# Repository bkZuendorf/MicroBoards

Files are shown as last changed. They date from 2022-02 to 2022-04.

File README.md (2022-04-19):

# CRBK-MicroBoards

In diesem Projekt werden µC-Boards bereitgestellt, die im Rahmen des Unterrichts am CRBK entstanden sind.

## Integration der Boards in die Arduino IDE
Um die Boards innerhalb der Arduino IDE nutzen zu können, müssen folgende Schritte durchgeführt werden:
- Ergänzung der Boardverwalter URL in der Arduino-IDE (unter Datei/Voreinstellungen) um die Adresse zur JSON Datei: https://raw.githubusercontent.com/bkZuendorf/MicroBoards/main/package_crbk_index.json
- Öffne in der Arduino-IDE unter Werkzeuge/Board/ den Boardverwalter
- Suche nach CRBK
- Installiere CRBK Mikrocontroller Boards

## Boards
Im Augenblick steht ein einfaches Board zur Verfügung.

### TinyRuler
Der TinyRuler ist das erste Board des CRBKs auf Basis eine ATTiny 84A. Ziel war es ein einfaches Board zum direkten Programmieren über den USB-Port zu erzeugen. Das Board ist lediglich dazu gedacht 5 LEDs abhängig von einem Lagesensor anzusprechen. Der erste Entwurf sah die Verwendung der Platinen innerhalb eines 3-D gedruckten Lineals vor. So kann mit Anheben des Lineals die Animation der LEDs verändert werden. Besonderes Augenmerk galt der energiesparenden Umsetzung der Lösung.
Das Board benötigt im Tiefschlafmodus weniger als 1µA und lässt so mit einer 200mAh Knopfzelle eine mehrmonatige Nutzung zu. 

Im Rahmen der Ausrichtung des Girls' Day wurde die Platine als Bestandteil eines Lineals vorgesehen. Das "Meldelineal" für Schülerinnen und Schüler wurde wir folgt gestaltet:
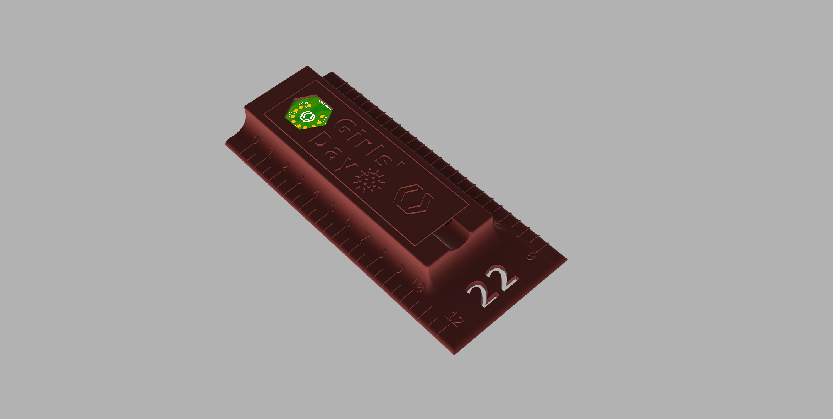
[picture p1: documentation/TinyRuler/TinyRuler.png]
Design für den Girls' Day


Das [Video](https://www.abitur-am-berufskolleg.info/wp-content/uploads/2021/11/TinyRuler.mp4) zeigt das geplante Aussehen in einer ersten Version.

Ein Video des fertigen Exponats folgt ...

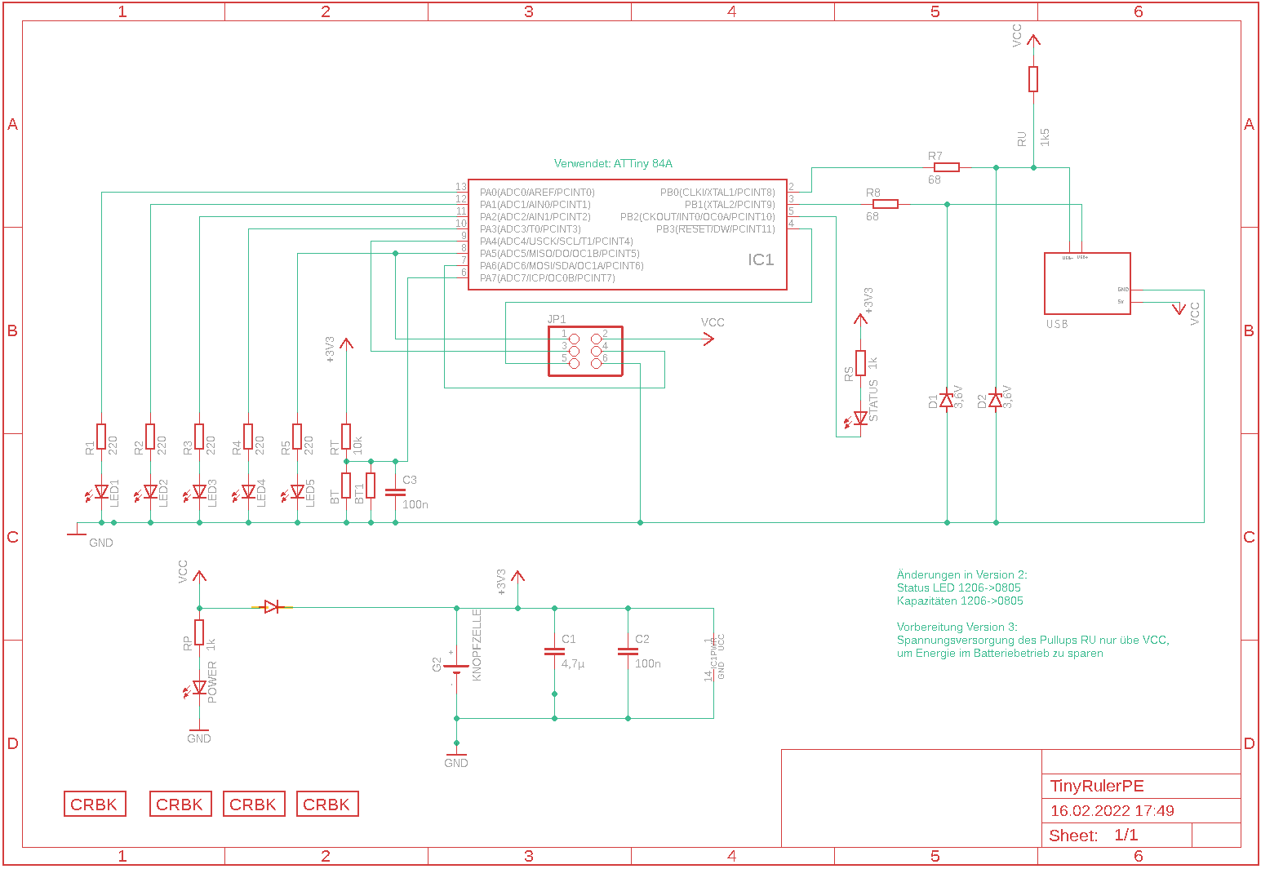
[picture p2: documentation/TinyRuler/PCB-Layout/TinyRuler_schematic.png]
Schematic

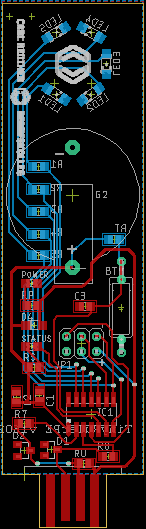
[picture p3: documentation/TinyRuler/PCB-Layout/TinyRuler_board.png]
Board


Das [Eagle Layout](https://github.com/bkZuendorf/MicroBoards/tree/main/documentation/TinyRuler/PCB-Layout) kann verwendet werden, um die Platine nachzubauen.
Die [Fusion CAD-Datei](https://github.com/bkZuendorf/MicroBoards/tree/main/documentation/TinyRuler/Fusion-Design) dient der Erzeugung einer 3D-Druck Datei.

#### Treiber
Zur Verwendung des TinyRuler ist die Installation eines Treibers erforderlich. Dies kann entsprechend der Anleitung auf der Original-Bootloader Seite [Micronucleus](https://github.com/micronucleus/micronucleus/tree/master/windows_driver_installer) erfolgen.

#### Erstprogrammierung
Bevor das Board über die USB-Schnittstelle programmiert werden kann, muss einmalig ein Bootloader programmiert werde,
Der Bootloader muss mit einem Programmieradapter mit üblichen Mitteln (avrdude, Microchip-Studio, ...) programmiert werden. Das fertig [compiliertes Produktionsfile](https://github.com/bkZuendorf/MicroBoards/blob/main/ATTiny84_productionfile.elf) steht zur Verfügung.
Zusätzlich müssen die Fuses geändert werden:
- SELFPRGEN: enable 
- WDTON: disable (keinen Watchdog, wird nicht genutzt und benötigt im Tiefschlaf zu viel Energie)
- BODLEVEL: disable (Brown-out detection deaktiviern, damit µC auch mit geringer Spannung arbeitet)

Am Ende sollten die Fuse-Register folgende Werte haben:
- EXTENDED: 0xFE
- HIGH: 0xDF
- LOW: 0xE2

#### Programmierung
Nach Integration in die Arduino IDE (s.o.) stehen einige [Beispiele](https://github.com/bkZuendorf/MicroBoards/tree/main/CRBK-MicroBoards/libraries/TinyRuler/examples) zur Verfügung. Mit recht einfachen Mitteln können die LEDs programmiert, Animationen erzeugt werden und der µC in einen energiesparenden Modus versetzt werden.

Das untenstehende Beispiel zeigt eine typische Anwendung der TinyRuler-Bibliothek
```
#include "TinyRuler.h" // Binde den Bibliothek-Header ein

TinyRuler ruler;  // Erstelle eine Instanz des Lineals

void setup() {
  ruler.init();  // Initialisiere das Lineal bei Start des µCs 
}

void loop()
{
  bool sensor = ruler.getSensor(); // ermittelt die Linealposition, true zeigt liegende Position an

  if(sensor) {
    // Lineal liegt
    ruler.reset(0);   // schalte LED 0 aus
    ruler.toggle(1);  // wechsle den Zustand der LED 1
    delay(500);
    ruler.toggle(2);  // wechsle den Zustand der LED 2
    delay(500);
  } else {
    // Lineal liegt nicht
    if(ruler.get(1)) {
      // wenn LED 1 leuchtet, schalte alle LEDs aus
      ruler.resetAll();
    } else {
      // wenn LED 1 nicht leuchtet, schalte alle LEDs an
      ruler.setAll();
    }
    delay(50);
  }
    
  // rufe handle auf, damit der Lagezustand ermittelt werden kann und 
  // sich das Lineal nach einer Zeit schlafen legt und automatisch wieder aufwacht
  // hier: Lasse Lineal 2,5 Sekunden nach dem Erkennen der Lage in den Schlafmodus wechseln
  ruler.handle(2500);
}
```

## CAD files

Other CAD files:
documentation/TinyRuler/Fusion-Design/TinyRuler.dwg

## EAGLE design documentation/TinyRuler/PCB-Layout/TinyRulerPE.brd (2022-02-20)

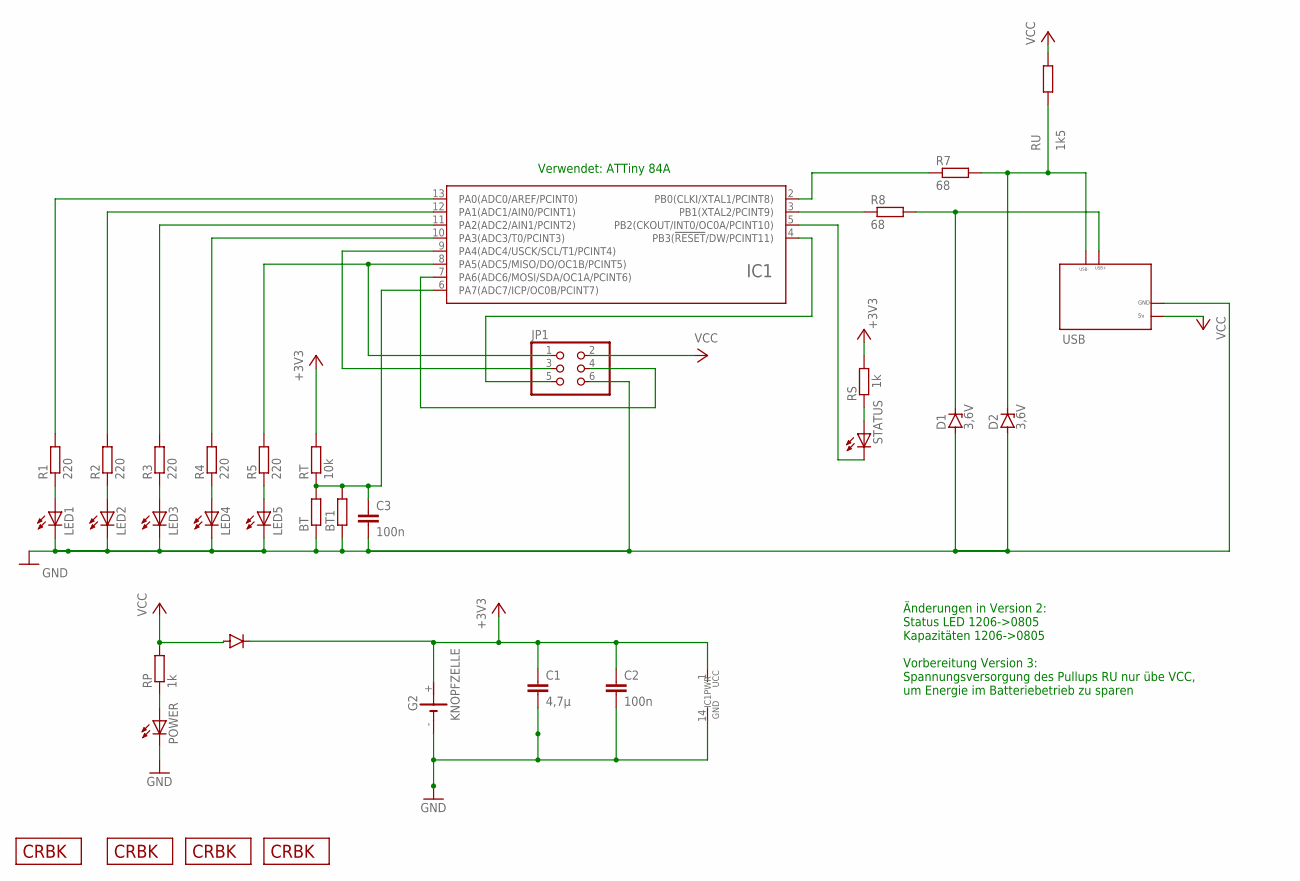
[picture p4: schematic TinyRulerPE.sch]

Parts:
BT: R-EU_0411/15; 0411/15
BT1: R-EU_0309/10; 0309/10
C1: 4,7µ; C0805
C2, C3: 100n; C0805
D1, D2: 3,6V; SOT23
D4: DIODE-SOD323-W; SOD323-W
G2: KNOPFZELLE; KZH20
IC1: ATTINY24/44/84-SSU; SOIC14
JP1: PINHD-2X3; 2X03
L1, L4: CRBKLOGO-2020TN_TEXT; CRBK-LOGO-2020-XS-TN-TEXT
L2, L3: CRBKLOGO-2020TN_S_BILD; CRBK-LOGO-2020-S-TN-BILD
LED1, LED2, LED3, LED4, LED5: LEDCHIPLED_1206; CHIPLED_1206
POWER: LEDCHIPLED_0805; CHIPLED_0805
R1, R2, R3, R4, R5: 220; R0805
R7, R8: 68; R0805
RP: 1k; R0805
RS: 1k; R0805
RT: 10k; R0805
RU: 1k5; R0805
STATUS: LEDCHIPLED_0805; CHIPLED_0805
USB: USBCONNECTOR

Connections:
+3V3: C1.1, C2.1, D4.C, G2.+, IC1.1 (UCC), RS.2, RT.2
GND: BT.1, BT1.1, C1.2, C2.2, C3.2, D1.1 (A), D2.1 (A), G2.-, IC1.14 (GND), JP1.6, LED1.C, LED2.C, LED3.C, LED4.C, LED5.C, POWER.C, USB.GND
unnamed: LED2.A, R2.1
unnamed: LED1.A, R1.1
unnamed: LED3.A, R3.1
unnamed: LED4.A, R4.1
unnamed: LED5.A, R5.1
unnamed: IC1.9 (PA4(ADC4/USCK/SCL/T1/PCINT4)), JP1.3
unnamed: IC1.8 (PA5(ADC5/MISO/DO/OC1B/PCINT5)), JP1.1, R5.2
unnamed: IC1.13 (PA0(ADC0/AREF/PCINT0)), R1.2
unnamed: IC1.4 (PB3(!RESET!/DW/PCINT11)), JP1.5
unnamed: BT.2, BT1.2, C3.1, IC1.6 (PA7(ADC7/ICP/OC0B/PCINT7)), RT.1
unnamed: IC1.12 (PA1(ADC1/AIN0/PCINT1)), R2.2
unnamed: D1.3 (C), R8.2, USB.USB+
unnamed: D2.3 (C), R7.2, RU.1, USB.USB-
unnamed: IC1.11 (PA2(ADC2/AIN1/PCINT2)), R3.2
unnamed: POWER.A, RP.1
unnamed: IC1.5 (PB2(CKOUT/INT0/OC0A/PCINT10)), STATUS.C
unnamed: IC1.7 (PA6(ADC6/MOSI/SDA/OC1A/PCINT6)), JP1.4
unnamed: RS.1, STATUS.A
unnamed: IC1.10 (PA3(ADC3/T0/PCINT3)), R4.2
unnamed: IC1.2 (PB0(CLKI/XTAL1/PCINT8)), R7.1
unnamed: IC1.3 (PB1(XTAL2/PCINT9)), R8.1
VCC: D4.A, JP1.2, RP.2, RU.2, USB.+5V (5V)

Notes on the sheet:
Änderungen in Version 2: Status LED 1206->0805 Kapazitäten 1206->0805 Vorbereitung Version 3: Spannungsversorgung des Pullups RU nur übe VCC, um Energie im Batteriebetrieb zu sparen
Verwendet: ATTiny 84A

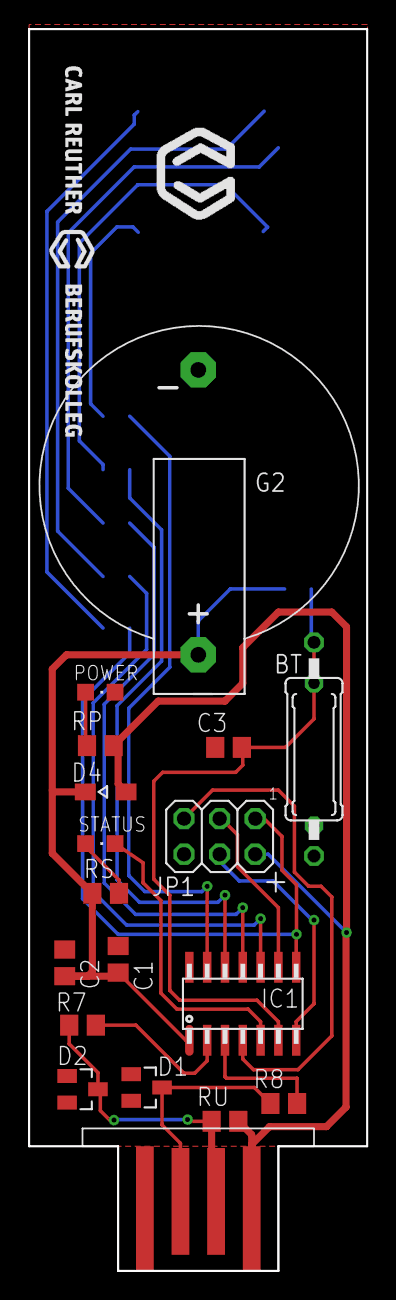
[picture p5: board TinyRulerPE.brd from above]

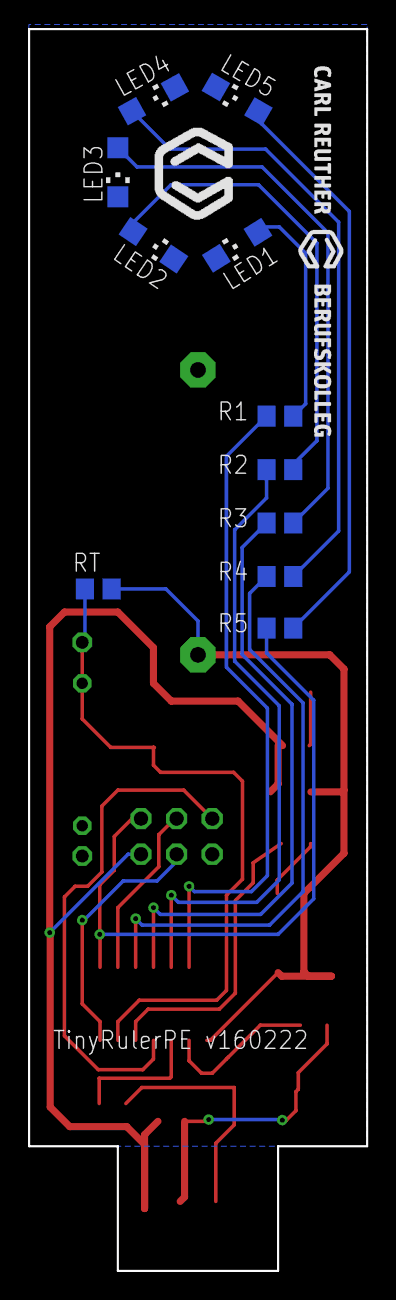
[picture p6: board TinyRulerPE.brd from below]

Board: 2 copper layers, 24.1 x 88.6 mm, 34 parts (13 on the bottom side), 24 nets.

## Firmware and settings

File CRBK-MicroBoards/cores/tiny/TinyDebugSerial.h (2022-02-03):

/*==============================================================================

  TinyDebugSerial.h - Tiny write-only software serial.

  Copyright 2010 Rowdy Dog Software.

  This file is part of Arduino-Tiny.

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
==============================================================================*/

#ifndef TinyDebugSerial_h
#define TinyDebugSerial_h

#include <inttypes.h>

#include "binary.h"
#include "core_build_options.h"
#include "Stream.h"


class TinyDebugSerialWriter;
class TinyDebugSerial;


class TinyDebugSerialWriter
{
  protected:

    virtual void init( void )
    {
    }

    virtual void write( uint8_t )
    {
    }

  friend class TinyDebugSerial;
};

void TinyDebugSerialWriterInternalBug( void ) __attribute__((error("Serial (TinyDebugSerial) has an internal problem.  Contact the developer.")));

__attribute__((always_inline, unused)) static inline void TinyDebugSerialWriterBangOneByte( uint8_t value, uint8_t SER_REG, uint8_t SER_BIT, uint8_t lom, uint8_t him, uint8_t oloops, uint8_t iloops, uint8_t nops )
{
  if ( __builtin_constant_p( SER_REG ) 
      && __builtin_constant_p( SER_BIT ) 
      && __builtin_constant_p( lom ) 
      && __builtin_constant_p( him )
      && __builtin_constant_p( oloops ) 
      && __builtin_constant_p( iloops ) 
      && __builtin_constant_p( nops ) )
  {
      uint8_t i;
      uint8_t j;
      uint8_t ol;
      uint8_t il;
      uint8_t b;  // Initialized to the low bits
      uint8_t hib;
      uint8_t m;
      
      b   = ((value << 1) & 0x1F);
      hib = ((value >> 4) & 0x1F) | 0x10;
      
      asm volatile
      (
        "ldi   %[j], 2"                           "\n\t"
        "ldi   %[i], 5"                           "\n\t"
        "ldi   %[m], %[lom]"                      "\n\t"

        // Note: 8 MHz, 9600 baud ---> disabling interrupts does not appear to be necessary

        "cli"                                     "\n\t"

        "rjmp  L%=ntop"                           "\n\t"

      "L%=btop: "
        "nop"                                     "\n\t"      // ---> 7
        "nop"                                     "\n\t"      //
        "nop"                                     "\n\t"      //
        "nop"                                     "\n\t"      //
        "nop"                                     "\n\t"      //
        "nop"                                     "\n\t"      //
        "nop"                                     "\n\t"      //

      "L%=ntop: "
        "ror   %[b]"                              "\n\t"      // ---> 1
        
        "brcs  L%=bxh"                            "\n\t"      // 1  (not taken) 
        "cbi   %[serreg], %[serbit]"              "\n\t"      // 2
        "rjmp  L%=bxz"                            "\n\t"      // 2 
        
      "L%=bxh: "                                              // 2  (taken) 
        "sbi   %[serreg], %[serbit]"              "\n\t"      // 2
        "nop"                                     "\n\t"      // 1 

                                                              // ---> 5
      "L%=bxz: "

        "ror   %[m]"                              "\n\t"      // ---> 3 or 4 
        "brcc  L%=bnoe"                           "\n\t"      //
        "nop"                                     "\n\t"      //
        "nop"                                     "\n\t"      //
      "L%=bnoe: "

                                                              // ---> 1
      ".if %[oloops] >= 1"                        "\n\t"      // if oloops >= 1 then...
        "ldi   %[ol], %[oloops]"                  "\n\t"      // 4*oloops + oloops*(3*iloops) or oloops*((3*iloops)+4)
      "L%=odelay: "                               "\n\t"
      ".endif"                                    "\n\t"
        "ldi   %[il], %[iloops]"                  "\n\t"      // if oloops == 0 then...
      "L%=idelay: "                               "\n\t"      // (3*iloops)
        "dec   %[il]"                             "\n\t"
        "brne  L%=idelay"                         "\n\t"
        "nop"                                     "\n\t"
      ".if %[oloops] >= 1"                        "\n\t"
        "dec   %[ol]"                             "\n\t"
        "brne  L%=odelay"                         "\n\t"
        "nop"                                     "\n\t"
      ".endif"                                    "\n\t"

      ".if %[nops] >= 1"                          "\n\t"
        "nop"                                     "\n\t"      //
      ".endif"                                    "\n\t"
      ".if %[nops] >= 2"                          "\n\t"
        "nop"                                     "\n\t"      //
      ".endif"                                    "\n\t"

        "dec   %[i]"                              "\n\t"      // ---> 3
        "brne  L%=btop"                           "\n\t"      //
        "nop"                                     "\n\t"      //

        "dec   %[j]"                              "\n\t"      // ---> 7
        "breq  L%=bfin"                           "\n\t"      //
        "ldi   %[i], 5"                           "\n\t"      //
        "mov   %[b], %[hib]"                      "\n\t"      //
        "ldi   %[m], %[him]"                      "\n\t"      //
        "rjmp  L%=ntop"                           "\n\t"      //

      "L%=bfin: "

        "sei"                                     "\n\t"
        : 
          [i] "=&r" ( i ),
          [j] "=&r" ( j ),
          [ol] "=&r" ( ol ),
          [il] "=&r" ( il ),
          [m] "=&r" ( m )
        : 
          [b] "r" ( b ),
          [hib] "r" ( hib ),
          [serreg] "I" ( SER_REG ),
          [serbit] "M" ( SER_BIT ),
          [lom] "M" ( lom ),
          [him] "M" ( him ),
          [oloops] "M" ( oloops ),
          [iloops] "M" ( iloops ),
          [nops] "M" ( nops )
        :
          "r31",
          "r30"
      );
  }
  else
  {
    TinyDebugSerialWriterInternalBug();
  }
}


template
  <
    uint8_t SER_REG,
    uint8_t SER_BIT
  >
class TinyDebugSerialWriter_1_9600 : public TinyDebugSerialWriter
{
  protected:

    virtual void init( void )
    {
      asm volatile
      (
        "sbi   %[serreg]-1, %[serbit]"            "\n\t"
        "sbi   %[serreg], %[serbit]"              "\n\t"
        : 
        : 
          [serreg] "I" ( SER_REG ),
          [serbit] "I" ( SER_BIT )
        :
      );
    }

    virtual void write( uint8_t value )
    {
      TinyDebugSerialWriterBangOneByte( value, SER_REG, SER_BIT, B00100, B00010, 0, 28, 2 );
    }
};
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

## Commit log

2022-02-04 handle-Funktion zur Ŕealisierung des Schlafmodus
2022-02-06 Optimierung des Tiefschlafs
2022-02-17 AD Wandler ausgeschaltet für power save deep sleep
2022-02-20 Eagle Layout ergänzt
    [TinyRulerPE.brd, TinyRulerPE.sch]
2022-02-20 Fusion Datei ergänzt
    [TinyRuler.dwg]
2022-02-20 Animation überarbeitet
    Eagle Layout ergänzt
    Bild ergänzt
    Update README.md
    Fusion Datei ergänzt
    [TinyRuler.dwg, TinyRulerPE.brd, TinyRulerPE.sch]

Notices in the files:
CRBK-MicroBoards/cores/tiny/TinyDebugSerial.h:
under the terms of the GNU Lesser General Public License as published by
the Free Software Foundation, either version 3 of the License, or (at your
